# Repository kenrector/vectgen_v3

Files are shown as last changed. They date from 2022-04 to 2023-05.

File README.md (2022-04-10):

# vectgen_v3
kicad project for Wells-Gardner display controller

This is an ESP32 based interface to the Wells-Gardner 15v2000 BW X-Y display perhaps originally found
in the Atari Asteroids and Lunar Lander cocktail style arcade games.  The display is controlled by
X-Y voltages in the ranges +/- 0-10v and Z voltage 0-5v. 

The ESP32 processor is resident on a Wiretag WT32-ETH01 board and interfaces with client software via
the LAN connection.

Input commands from the client are move, draw, and zero, with related 12bit vector values sent to
X and Y MCP4922 DAC channels via the SPI interface.

Output from the DAC is translated to a bipolar voltage input to op amp integrator.  Integrator output is
input to the WG display.

Integrator input is switched by ADG201S CMOS switches controlled by the ESP32 software.  The integrators
are reset to zero by ADG201s switches also controlled by the ESP32.

A Z axis control to switch the CRT beam is provided by simple transistor logic.

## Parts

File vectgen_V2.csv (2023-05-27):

Source: | /Users/admin/Development/vectgen/vectgen_v3.old/vectgen_V2.kicad_sch
Date: | Tuesday, May 23, 2023 at 07:13:00 PM
Tool: | Eeschema (6.0.10-0)
Generator: | /Applications/KiCad/KiCad.app/Contents/SharedSupport/plugins/bom_csv_grouped_by_value.py
Component Count: | 47
Individual Components:
Item | Qty | Reference(s) | Value | LibPart | Footprint | Datasheet
 |  | C1 | .01uF | Device:C | Capacitor_THT:C_Disc_D5.0mm_W2.5mm_P5.00mm | ~
 |  | C2 | .01uF | Device:C | Capacitor_THT:C_Disc_D5.0mm_W2.5mm_P5.00mm | ~
 |  | C3 | .01uF | Device:C | Capacitor_THT:C_Disc_D5.0mm_W2.5mm_P5.00mm | ~
 |  | C4 | .01uF | Device:C | Capacitor_THT:C_Disc_D5.0mm_W2.5mm_P5.00mm | ~
 |  | C5 | .1uF | Device:C | Capacitor_THT:C_Disc_D5.0mm_W2.5mm_P5.00mm | ~
 |  | C6 | 10uF | Device:C | Capacitor_THT:C_Disc_D5.0mm_W2.5mm_P5.00mm | ~
 |  | C7 | 10uF | Device:C | Capacitor_THT:C_Disc_D5.0mm_W2.5mm_P5.00mm | ~
 |  | C8 | .1uF | Device:C | Capacitor_THT:C_Disc_D5.0mm_W2.5mm_P5.00mm | ~
 |  | C9 | 150pF | Device:C | Capacitor_THT:C_Disc_D5.0mm_W2.5mm_P5.00mm | ~
 |  | C10 | 150pF | Device:C | Capacitor_THT:C_Disc_D5.0mm_W2.5mm_P5.00mm | ~
 |  | C11 | .1uF | Device:C | Capacitor_THT:C_Disc_D5.0mm_W2.5mm_P5.00mm | ~
 |  | C12 | .1uF | Device:C | Capacitor_THT:C_Disc_D5.0mm_W2.5mm_P5.00mm | ~
 |  | C13 | .01uF | Device:C | Capacitor_THT:C_Rect_L11.0mm_W2.8mm_P10.00mm_MKT | ~
 |  | C14 | .01uF | Device:C | Capacitor_THT:C_Rect_L11.0mm_W2.8mm_P10.00mm_MKT | ~
 |  | H1 | MountingHole | Mechanical:MountingHole | MountingHole:MountingHole_3.7mm_Pad_TopBottom | ~
 |  | H2 | MountingHole | Mechanical:MountingHole | MountingHole:MountingHole_3.7mm_Pad_TopBottom | ~
 |  | H3 | MountingHole | Mechanical:MountingHole | MountingHole:MountingHole_3.7mm_Pad_TopBottom | ~
 |  | H4 | MountingHole | Mechanical:MountingHole | MountingHole:MountingHole_3.7mm_Pad_TopBottom | ~
 |  | IC1 | ADG201A | vectgen_V2-rescue:ADG202A-vectgen_V2-rescue-vectgen_V2-rescue | Package_DIP:DIP-16_W7.62mm
 |  | IC2 | LF347D | vectgen_V2-rescue:LF347D-vectgen_V2-rescue-vectgen_V2-rescue | linear2-SO14
 |  | J1 | USB INTERFACE | Connector:Conn_01x02_Male | Connector_PinHeader_2.54mm:PinHeader_1x02_P2.54mm_Vertical | ~
 |  | J2 | Screw_Terminal_01x04 | Connector:Screw_Terminal_01x04 | TerminalBlock:TerminalBlock_bornier-4_P5.08mm | ~
 |  | J3 | Screw_Terminal_01x04 | Connector:Screw_Terminal_01x04 | TerminalBlock:TerminalBlock_bornier-4_P5.08mm | ~
 |  | JP1 | FLASH_EN | Jumper:Jumper_2_Open | Connector_PinHeader_2.54mm:PinHeader_1x02_P2.54mm_Vertical | ~
 |  | Q1 | 2N3904 | Device:Q_NPN_BCE | Package_TO_SOT_THT:TO-92 | ~
 |  | Q2 | 2N3904 | Device:Q_NPN_BCE | Package_TO_SOT_THT:TO-92 | ~
 |  | R1 | 10K | Device:R | Resistor_THT:R_Axial_DIN0204_L3.6mm_D1.6mm_P7.62mm_Horizontal | ~
 |  | R2 | 10K | Device:R | Resistor_THT:R_Axial_DIN0204_L3.6mm_D1.6mm_P7.62mm_Horizontal | ~
 |  | R3 | 15K | Device:R | Resistor_THT:R_Axial_DIN0204_L3.6mm_D1.6mm_P7.62mm_Horizontal | ~
 |  | R4 | 15K | Device:R | Resistor_THT:R_Axial_DIN0204_L3.6mm_D1.6mm_P7.62mm_Horizontal | ~
 |  | R5 | 30K | Device:R | Resistor_THT:R_Axial_DIN0204_L3.6mm_D1.6mm_P7.62mm_Horizontal | ~
 |  | R6 | 30K | Device:R | Resistor_THT:R_Axial_DIN0204_L3.6mm_D1.6mm_P7.62mm_Horizontal | ~
 |  | R7 | 2.2K | Device:R | Resistor_THT:R_Axial_DIN0204_L3.6mm_D1.6mm_P7.62mm_Horizontal | ~
 |  | R8 | 10K | Device:R | Resistor_THT:R_Axial_DIN0204_L3.6mm_D1.6mm_P7.62mm_Horizontal | ~
 |  | R9 | 10K | Device:R | Resistor_THT:R_Axial_DIN0204_L3.6mm_D1.6mm_P7.62mm_Horizontal | ~
 |  | R10 | 27 | Device:R | Resistor_THT:R_Axial_DIN0204_L3.6mm_D1.6mm_P7.62mm_Horizontal | ~
 |  | R11 | 3.3M | Device:R | Resistor_THT:R_Axial_DIN0204_L3.6mm_D1.6mm_P7.62mm_Horizontal | ~
 |  | R12 | 3.3M | Device:R | Resistor_THT:R_Axial_DIN0204_L3.6mm_D1.6mm_P7.62mm_Horizontal | ~
 |  | R13 | 220 | Device:R | Resistor_THT:R_Axial_DIN0204_L3.6mm_D1.6mm_P7.62mm_Horizontal | ~
 |  | R14 | 220 | Device:R | Resistor_THT:R_Axial_DIN0204_L3.6mm_D1.6mm_P7.62mm_Horizontal | ~
 |  | RV1 | 10K | vectgen_V2-rescue:POT-vectgen_V2-rescue-vectgen_V2-rescue | Potentiometer_THT:Potentiometer_Bourns_3296W_Vertical
 |  | RV2 | 10K | vectgen_V2-rescue:POT-vectgen_V2-rescue-vectgen_V2-rescue | Potentiometer_THT:Potentiometer_Bourns_3296W_Vertical
 |  | RV3 | 10K | vectgen_V2-rescue:POT-vectgen_V2-rescue-vectgen_V2-rescue | Potentiometer_THT:Potentiometer_Bourns_3296W_Vertical
 |  | SW1 | RESET | vectgen_V2-rescue:SW_PUSH-vectgen_V2-rescue-vectgen_V2-rescue | Button_Switch_THT:SW_DIP_SPSTx01_Piano_10.8x4.1mm_W7.62mm_P2.54mm
 |  | U1 | WT32-ETH01 | vectgen_V2-rescue:WT32-ETH01 | vectgen_v3.my_library:WT32-ETH01
 |  | U2 | MCP4922 | Analog_DAC:MCP4922 | Package_DIP:DIP-14_W7.62mm | http://ww1.microchip.com/downloads/en/DeviceDoc/22250A.pdf
 |  | U3 | L4931-3.3 | Regulator_Linear:LM2931AZ-5.0_TO92 | Package_TO_SOT_THT:TO-92_Inline | http://www.ti.com/lit/ds/symlink/lm2931-n.pdf
Collated Components:
Item | Qty | Reference(s) | Value | LibPart | Footprint | Datasheet
1 | 4 | C1, C2, C3, C4 | .01uF | Device:C | Capacitor_THT:C_Disc_D5.0mm_W2.5mm_P5.00mm | ~
2 | 4 | C5, C8, C11, C12 | .1uF | Device:C | Capacitor_THT:C_Disc_D5.0mm_W2.5mm_P5.00mm | ~
3 | 2 | C6, C7 | 10uF | Device:C | Capacitor_THT:C_Disc_D5.0mm_W2.5mm_P5.00mm | ~
4 | 2 | C9, C10 | 150pF | Device:C | Capacitor_THT:C_Disc_D5.0mm_W2.5mm_P5.00mm | ~
5 | 2 | C13, C14 | .01uF | Device:C | Capacitor_THT:C_Rect_L11.0mm_W2.8mm_P10.00mm_MKT | ~
6 | 4 | H1, H2, H3, H4 | MountingHole | Mechanical:MountingHole | MountingHole:MountingHole_3.7mm_Pad_TopBottom | ~
7 | 1 | IC1 | ADG201A | vectgen_V2-rescue:ADG202A-vectgen_V2-rescue-vectgen_V2-rescue | Package_DIP:DIP-16_W7.62mm
8 | 1 | IC2 | LF347D | vectgen_V2-rescue:LF347D-vectgen_V2-rescue-vectgen_V2-rescue | linear2-SO14
9 | 1 | J1 | USB INTERFACE | Connector:Conn_01x02_Male | Connector_PinHeader_2.54mm:PinHeader_1x02_P2.54mm_Vertical | ~
10 | 2 | J2, J3 | Screw_Terminal_01x04 | Connector:Screw_Terminal_01x04 | TerminalBlock:TerminalBlock_bornier-4_P5.08mm | ~
11 | 1 | JP1 | FLASH_EN | Jumper:Jumper_2_Open | Connector_PinHeader_2.54mm:PinHeader_1x02_P2.54mm_Vertical | ~
12 | 2 | Q1, Q2 | 2N3904 | Device:Q_NPN_BCE | Package_TO_SOT_THT:TO-92 | ~
13 | 4 | R1, R2, R8, R9 | 10K | Device:R | Resistor_THT:R_Axial_DIN0204_L3.6mm_D1.6mm_P7.62mm_Horizontal | ~
14 | 2 | R3, R4 | 15K | Device:R | Resistor_THT:R_Axial_DIN0204_L3.6mm_D1.6mm_P7.62mm_Horizontal | ~
15 | 2 | R5, R6 | 30K | Device:R | Resistor_THT:R_Axial_DIN0204_L3.6mm_D1.6mm_P7.62mm_Horizontal | ~
16 | 1 | R7 | 2.2K | Device:R | Resistor_THT:R_Axial_DIN0204_L3.6mm_D1.6mm_P7.62mm_Horizontal | ~
17 | 1 | R10 | 27 | Device:R | Resistor_THT:R_Axial_DIN0204_L3.6mm_D1.6mm_P7.62mm_Horizontal | ~
18 | 2 | R11, R12 | 3.3M | Device:R | Resistor_THT:R_Axial_DIN0204_L3.6mm_D1.6mm_P7.62mm_Horizontal | ~
19 | 2 | R13, R14 | 220 | Device:R | Resistor_THT:R_Axial_DIN0204_L3.6mm_D1.6mm_P7.62mm_Horizontal | ~
20 | 3 | RV1, RV2, RV3 | 10K | vectgen_V2-rescue:POT-vectgen_V2-rescue-vectgen_V2-rescue | Potentiometer_THT:Potentiometer_Bourns_3296W_Vertical
21 | 1 | SW1 | RESET | vectgen_V2-rescue:SW_PUSH-vectgen_V2-rescue-vectgen_V2-rescue | Button_Switch_THT:SW_DIP_SPSTx01_Piano_10.8x4.1mm_W7.62mm_P2.54mm
22 | 1 | U1 | WT32-ETH01 | vectgen_V2-rescue:WT32-ETH01 | vectgen_v3.my_library:WT32-ETH01
23 | 1 | U2 | MCP4922 | Analog_DAC:MCP4922 | Package_DIP:DIP-14_W7.62mm | http://ww1.microchip.com/downloads/en/DeviceDoc/22250A.pdf
24 | 1 | U3 | L4931-3.3 | Regulator_Linear:LM2931AZ-5.0_TO92 | Package_TO_SOT_THT:TO-92_Inline | http://www.ti.com/lit/ds/symlink/lm2931-n.pdf

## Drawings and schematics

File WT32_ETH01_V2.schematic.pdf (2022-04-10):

3V3

# GND GND GND

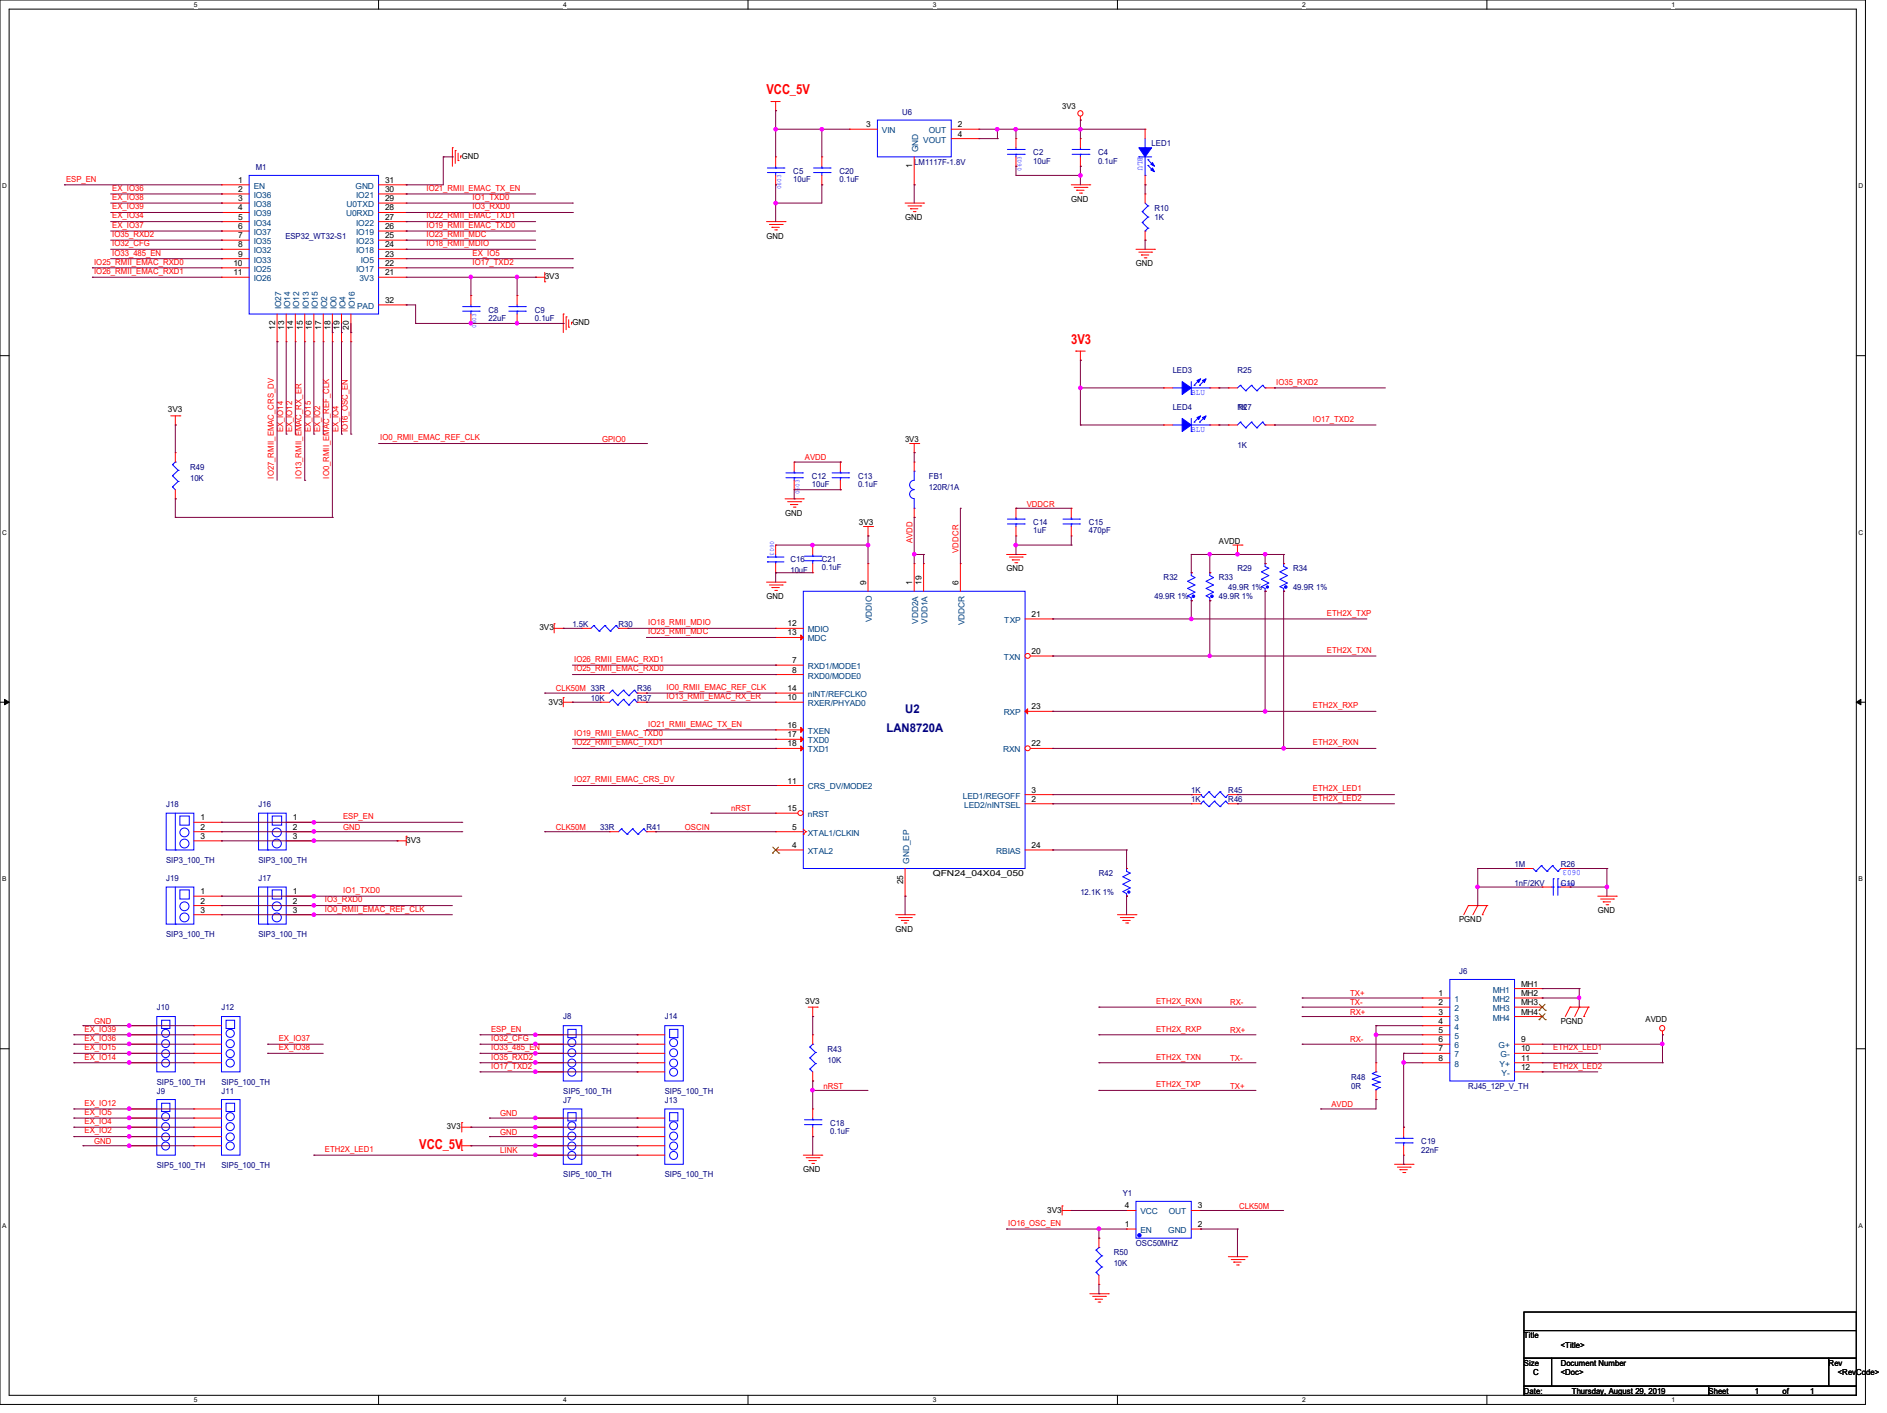
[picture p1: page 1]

6 RXP 23 RXN 22 TXN 20 TXP 21

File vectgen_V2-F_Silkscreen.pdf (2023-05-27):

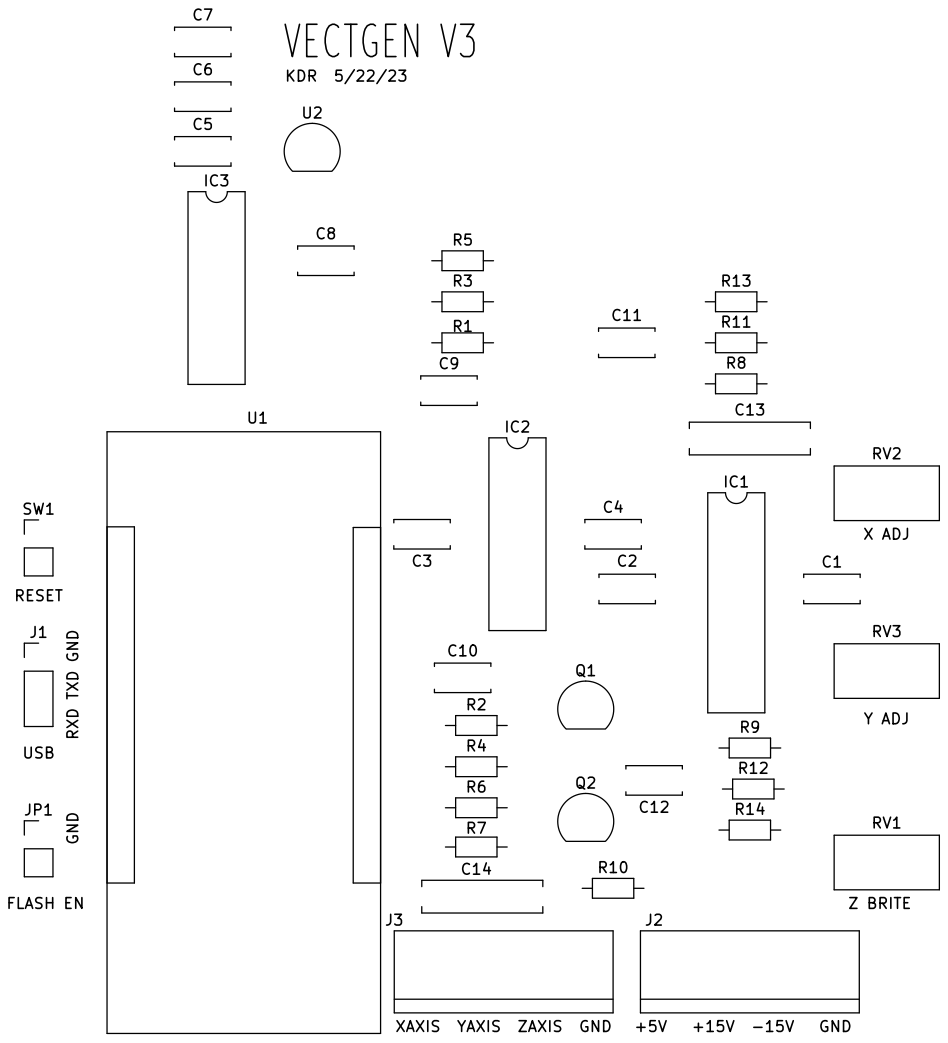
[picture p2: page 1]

KDR 5/22/23 XAXIS YAXIS ZAXIS GND

X ADJ RXD TXD GND

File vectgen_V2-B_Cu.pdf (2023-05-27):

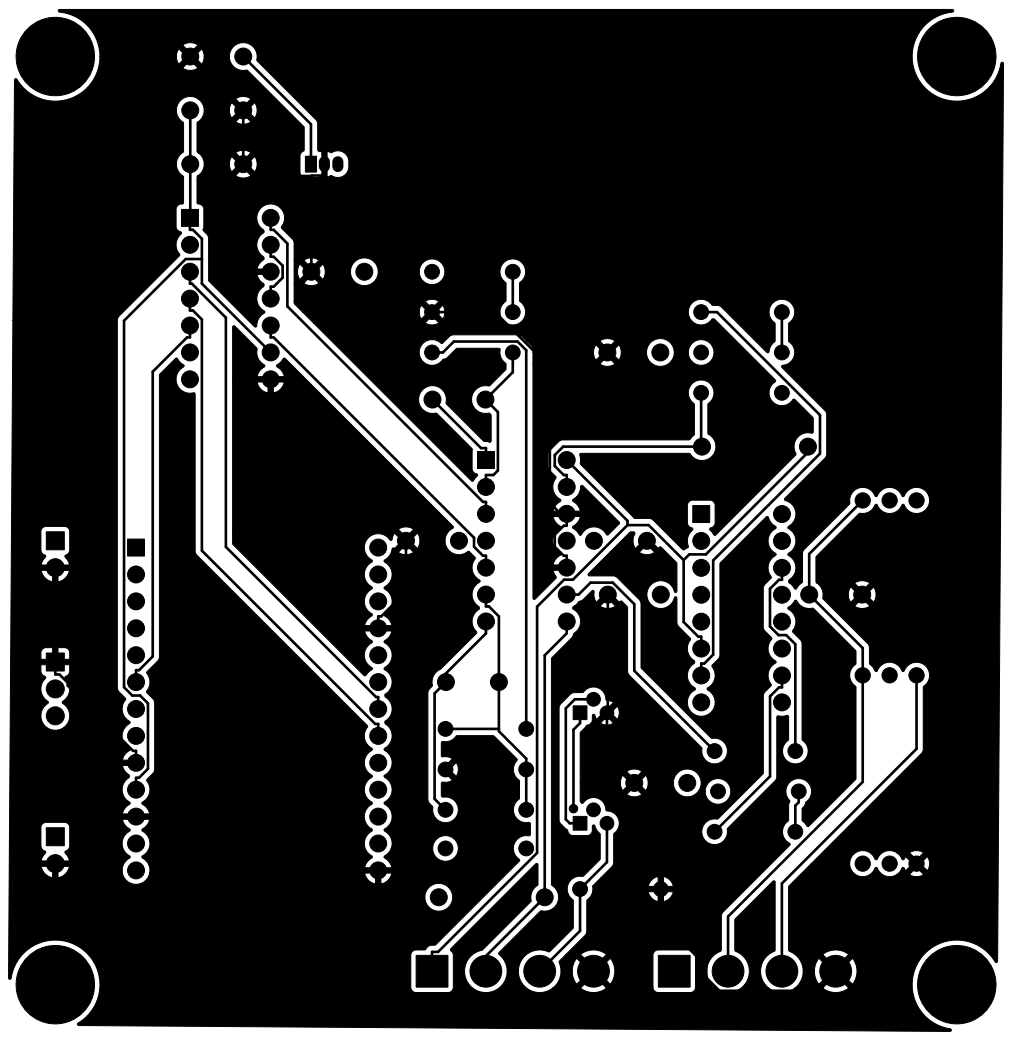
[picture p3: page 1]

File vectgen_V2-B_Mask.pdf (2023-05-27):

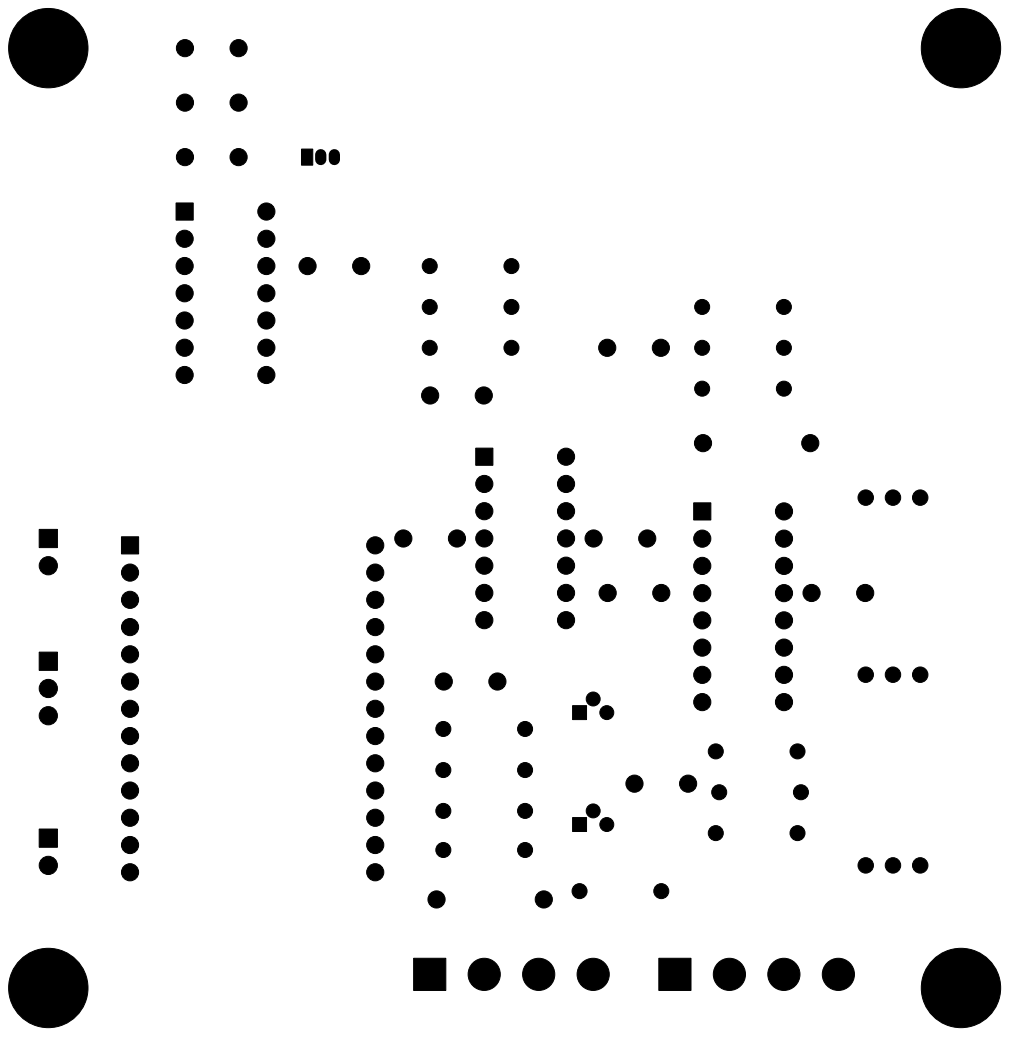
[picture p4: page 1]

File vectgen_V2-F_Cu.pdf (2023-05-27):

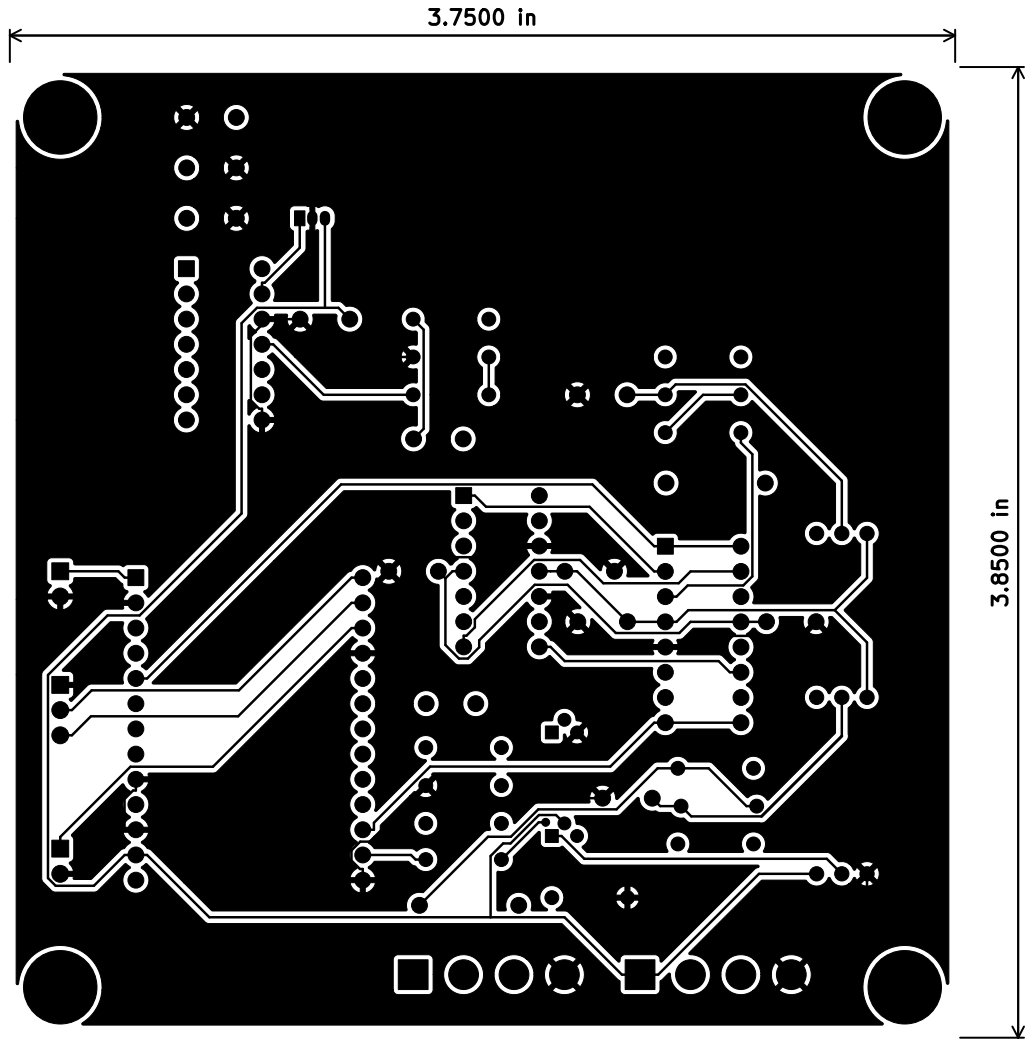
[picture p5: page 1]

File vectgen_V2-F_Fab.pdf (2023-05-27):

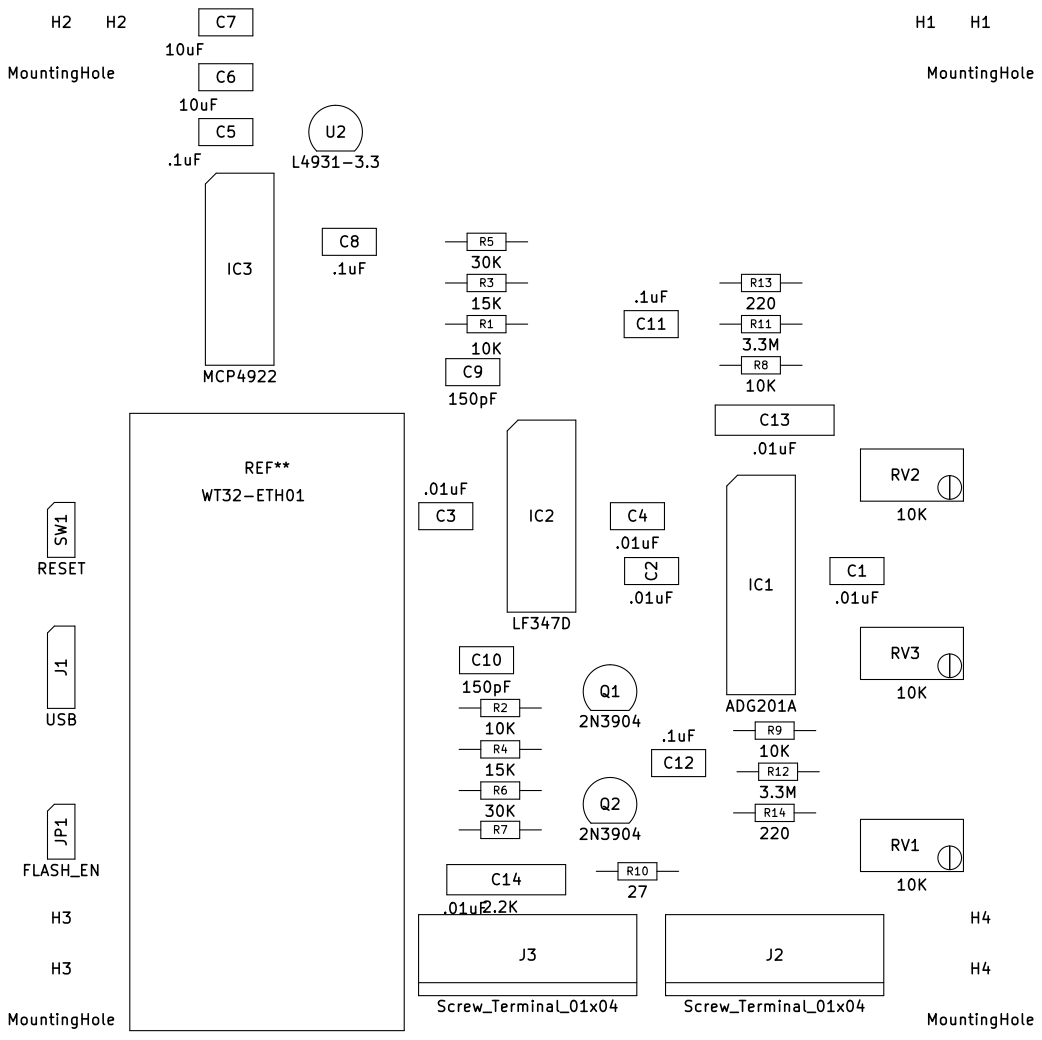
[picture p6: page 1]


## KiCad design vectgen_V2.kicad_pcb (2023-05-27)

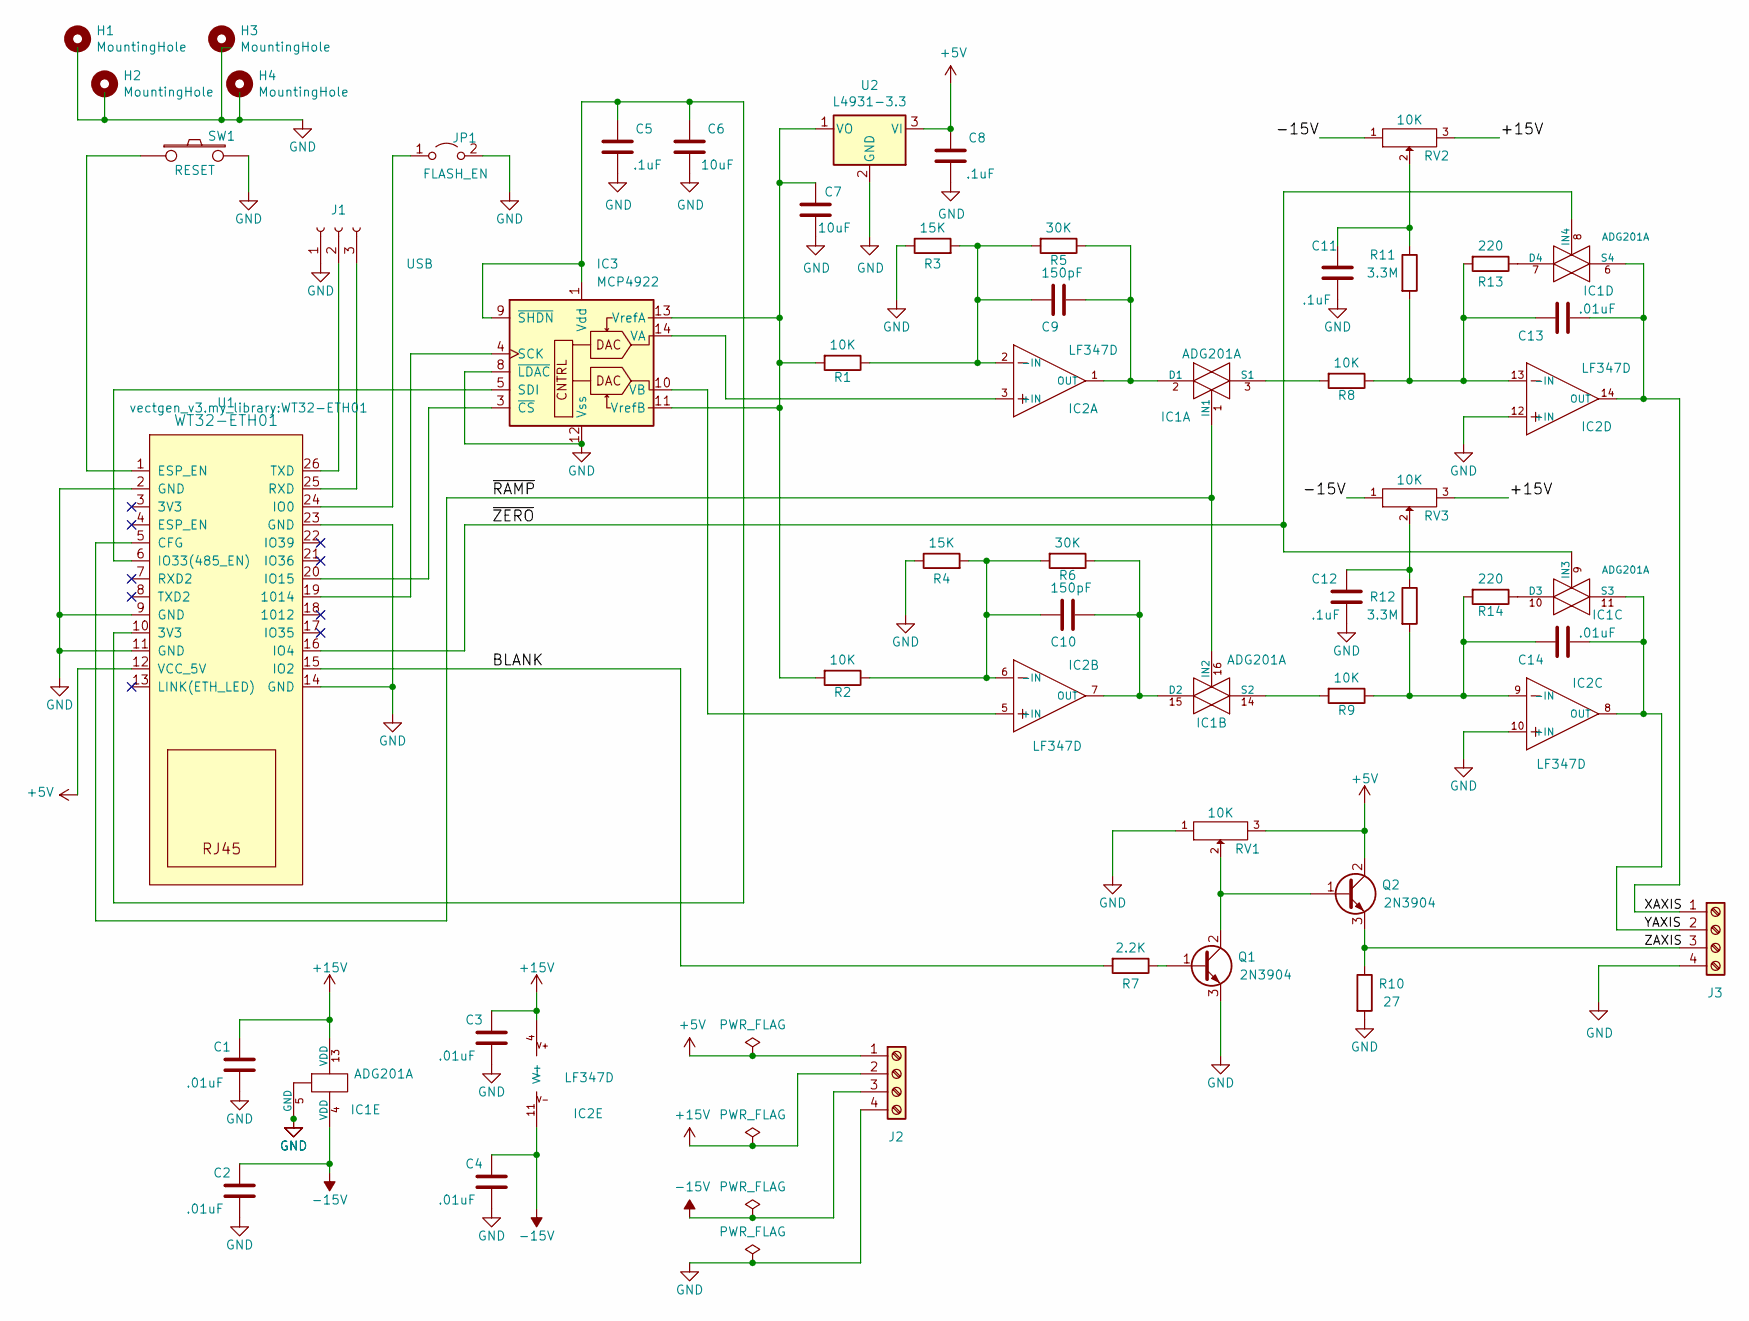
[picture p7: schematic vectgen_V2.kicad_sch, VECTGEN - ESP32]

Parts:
C1, C2, C3, C4: .01uF; C_Disc_D5.0mm_W2.5mm_P5.00mm
C5, C8, C11, C12: .1uF; C_Disc_D5.0mm_W2.5mm_P5.00mm
C6, C7: 10uF; C_Disc_D5.0mm_W2.5mm_P5.00mm
C9, C10: 150pF; C_Disc_D5.0mm_W2.5mm_P5.00mm
C13, C14: .01uF; C_Rect_L11.0mm_W2.8mm_P10.00mm_MKT
H1, H2, H3, H4: MountingHole; MountingHole_3.7mm_Pad_TopBottom
IC1: ADG201A; DIP-16_W7.62mm
IC2: LF347D; DIP-14_W7.62mm
IC3: MCP4922; DIP-14_W7.62mm
J1: USB; PinHeader_1x03_P2.54mm_Vertical
J2, J3: Screw_Terminal_01x04; TerminalBlock_bornier-4_P5.08mm
JP1: FLASH_EN; PinHeader_1x02_P2.54mm_Vertical
Q1, Q2: 2N3904; TO-92
R1, R2, R8, R9: 10K; R_Axial_DIN0204_L3.6mm_D1.6mm_P7.62mm_Horizontal
R3, R4: 15K; R_Axial_DIN0204_L3.6mm_D1.6mm_P7.62mm_Horizontal
R5, R6: 30K; R_Axial_DIN0204_L3.6mm_D1.6mm_P7.62mm_Horizontal
R7: 2.2K; R_Axial_DIN0204_L3.6mm_D1.6mm_P7.62mm_Horizontal
R10: 27; R_Axial_DIN0204_L3.6mm_D1.6mm_P7.62mm_Horizontal
R11, R12: 3.3M; R_Axial_DIN0204_L3.6mm_D1.6mm_P7.62mm_Horizontal
R13, R14: 220; R_Axial_DIN0204_L3.6mm_D1.6mm_P7.62mm_Horizontal
RV1, RV2, RV3: 10K; Potentiometer_Bourns_3296W_Vertical
SW1: RESET; PinHeader_1x02_P2.54mm_Vertical
U1: WT32-ETH01
U2: L4931-3.3; TO-92_Inline

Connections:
+5V: C8.2, J2.1, Q2.2 (C), RV1.3, U1.12 (VCC_5V), U2.3 (VI)
+15V: C1.1, C3.1, IC1.13 (VDD), IC2.4 (V+), J2.2, RV2.3, RV3.3
-15V: C2.1, C4.1, IC1.4 (VDD), IC2.11 (V-), J2.3, RV2.1, RV3.1
/BLANK: R7.2, U1.15 (IO2)
/XAXIS: C13.2, IC1.6 (S4), IC2.14 (OUT), J3.1
/YAXIS: C14.2, IC1.11 (S3), IC2.8 (OUT), J3.2
/ZAXIS: J3.3, Q2.3 (E), R10.1
/~RAMP: IC1.1 (IN1), IC1.16 (IN2), U1.5 (CFG)
/~ZERO: IC1.8 (IN4), IC1.9 (IN3), U1.16 (IO4)
GND: C1.2, C2.2, C3.2, C4.2, C5.1, C6.1, C7.1, C8.1, C11.2, C12.2, IC1.5 (GND), IC2.10 (+IN), IC2.12 (+IN), IC3.8 (~LDAC), IC3.12 (Vss), J1.1, J2.4, J3.4, JP1.2 (B), Q1.3 (E), R3.1, R4.1, R10.2, RV1.1, SW1.2, U1.2 (GND), U1.9 (GND), U1.11 (GND), U1.14 (GND), U1.23 (GND), U2.2 (GND)
unnamed: C5.2, C6.2, IC3.1 (Vdd), IC3.9 (~SHDN), U1.10 (3V3)
unnamed: C7.2, IC3.11 (VrefB), IC3.13 (VrefA), R1.2, R2.2, U2.1 (VO)
unnamed: C9.1, IC1.2 (D1), IC2.1 (OUT), R5.1
unnamed: C9.2, IC2.2 (-IN), R1.1, R3.2, R5.2
unnamed: C10.1, IC1.15 (D2), IC2.7 (OUT), R6.1
unnamed: C10.2, IC2.6 (-IN), R2.1, R4.2, R6.2
unnamed: C11.1, R11.1, RV2.2
unnamed: C12.1, R12.1, RV3.2
unnamed: C13.1, IC2.13 (-IN), R8.1, R11.2, R13.2
unnamed: C14.1, IC2.9 (-IN), R9.1, R12.2, R14.2
unnamed: IC1.3 (S1), R8.2
unnamed: IC1.7 (D4), R13.1
unnamed: IC1.10 (D3), R14.1
unnamed: IC1.14 (S2), R9.2
unnamed: IC2.3 (+IN), IC3.14 (VA)
unnamed: IC2.5 (+IN), IC3.10 (VB)
unnamed: IC3.3 (~CS), U1.20 (IO15)
unnamed: IC3.4 (SCK), U1.19 (1014)
unnamed: IC3.5 (SDI), U1.6 (IO33(485_EN))
unnamed: J1.2, U1.26 (TXD)
unnamed: J1.3, U1.25 (RXD)
unnamed: JP1.1 (A), U1.24 (IO0)
unnamed: Q1.1 (B), R7.1
unnamed: Q1.2 (C), Q2.1 (B), RV1.2
unnamed: SW1.1, U1.1 (ESP_EN)

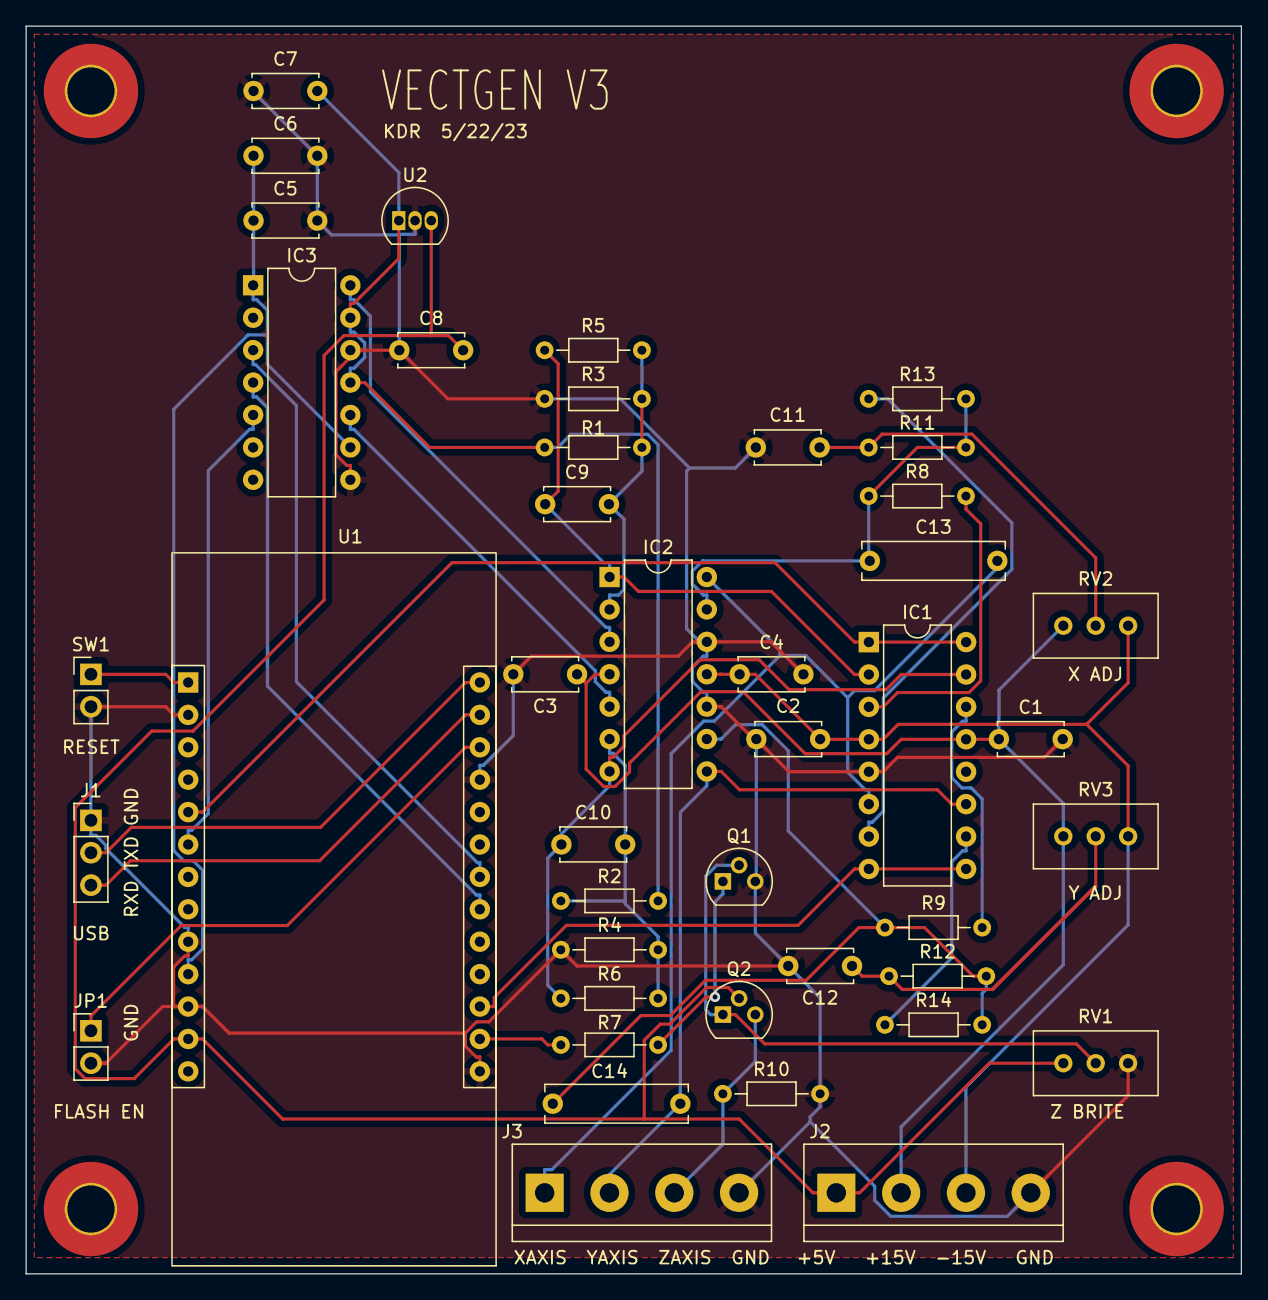
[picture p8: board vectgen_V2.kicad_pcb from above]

Board: 2 copper layers, 95.2 x 97.8 mm, 47 parts (0 on the bottom side), 35 nets.

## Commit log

2022-04-10 add WT32-ETH01 schematic and WG manual
2023-05-27 updated files used to build PCB
    [vectgen_V2-B_Cu.gbr, vectgen_V2-B_Mask.gbr, vectgen_V2-B_Silkscreen.gbr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]
